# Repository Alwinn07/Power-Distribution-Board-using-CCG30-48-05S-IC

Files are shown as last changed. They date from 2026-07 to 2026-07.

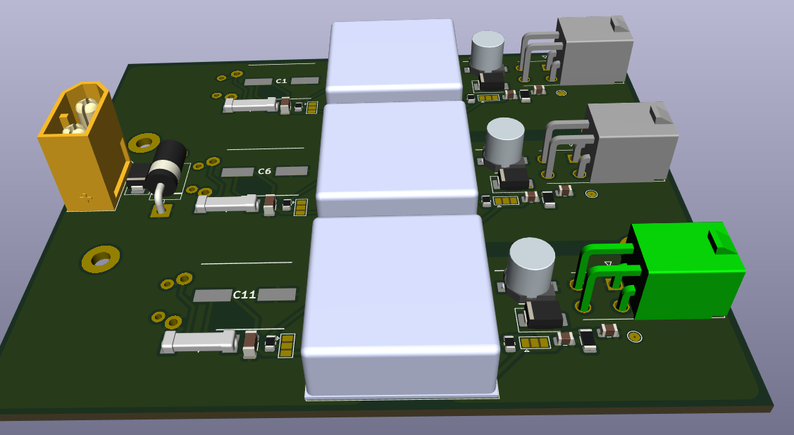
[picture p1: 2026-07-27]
Images/PCB_3D VIEW.png

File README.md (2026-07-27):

# Power-Distribution-Board-using-CCG30-48-05S-IC
An isolated 30 W DC-DC power converter PCB based on the CCG30 module, featuring surge protection, EMI filtering, current limiting, reverse polarity protection, and robust power input circuitry. Designed in KiCad with optimized PCB layout, thermal management, and manufacturability for reliable industrial applications.

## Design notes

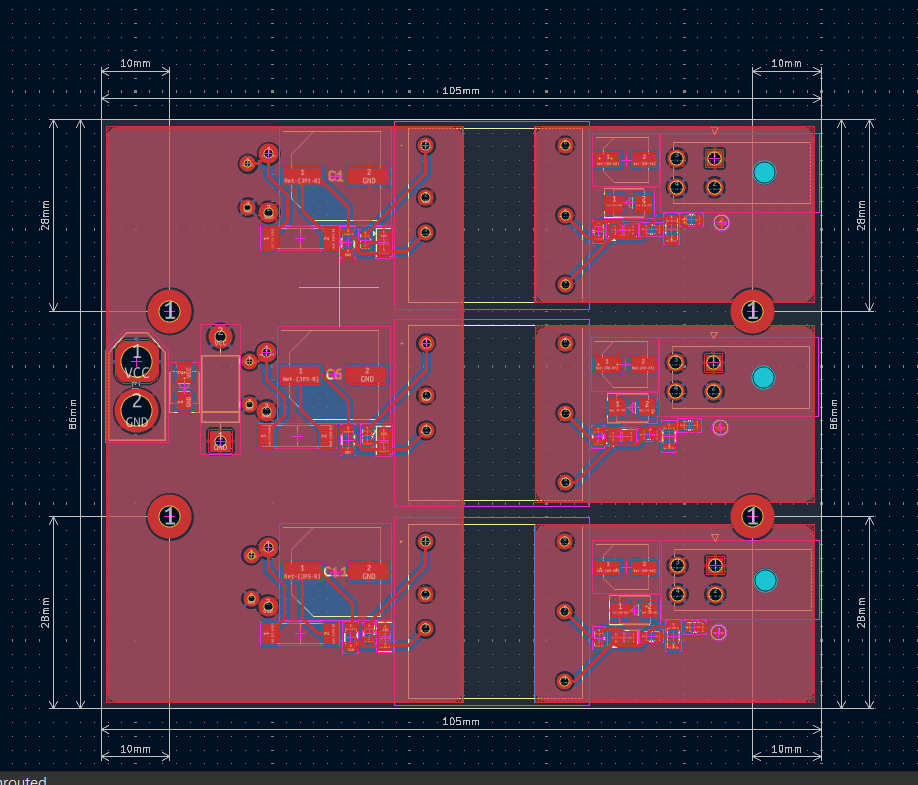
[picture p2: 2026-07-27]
Images/PCB_DESIGN.png

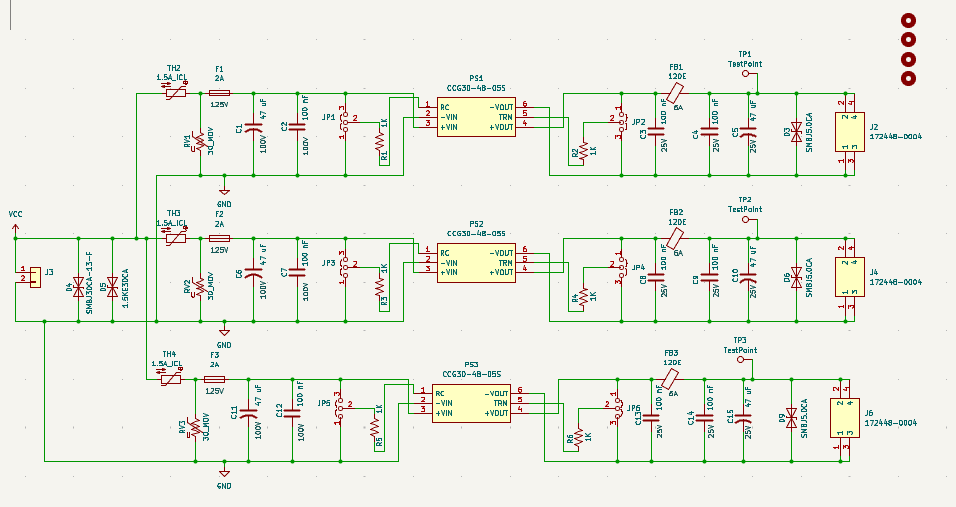
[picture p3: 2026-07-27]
Images/Schematics.png

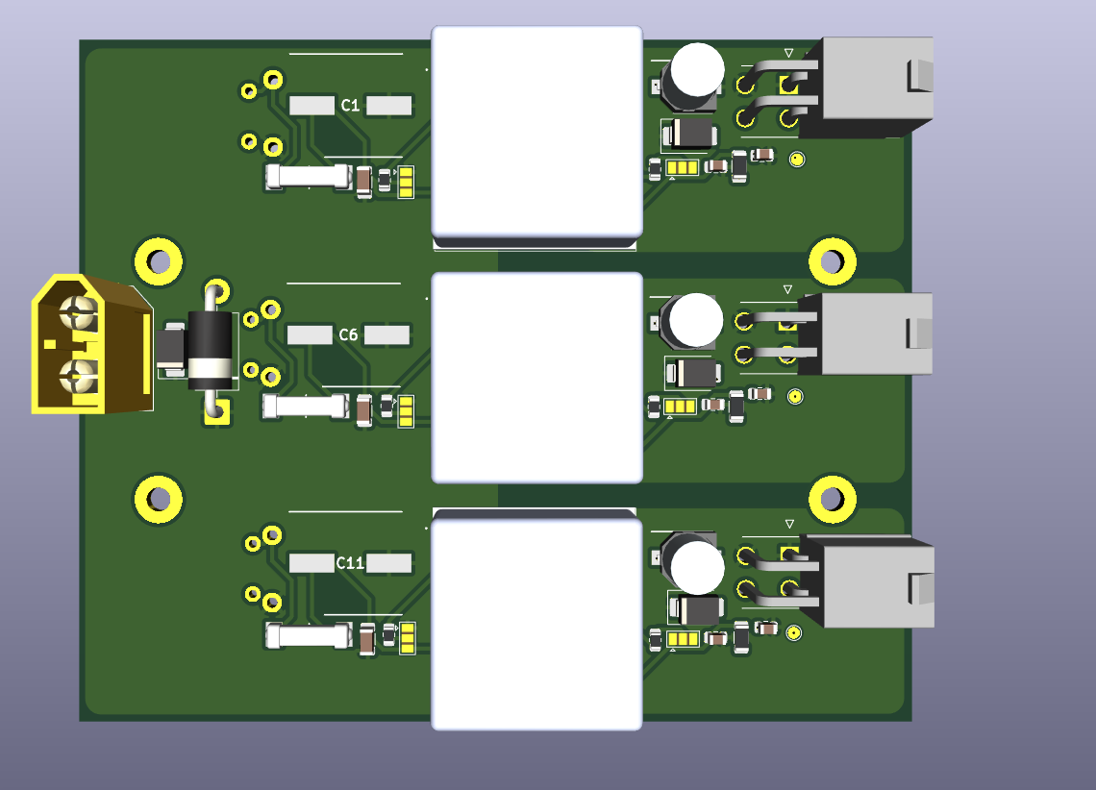
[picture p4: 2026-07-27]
Images/PCB_TOP.png

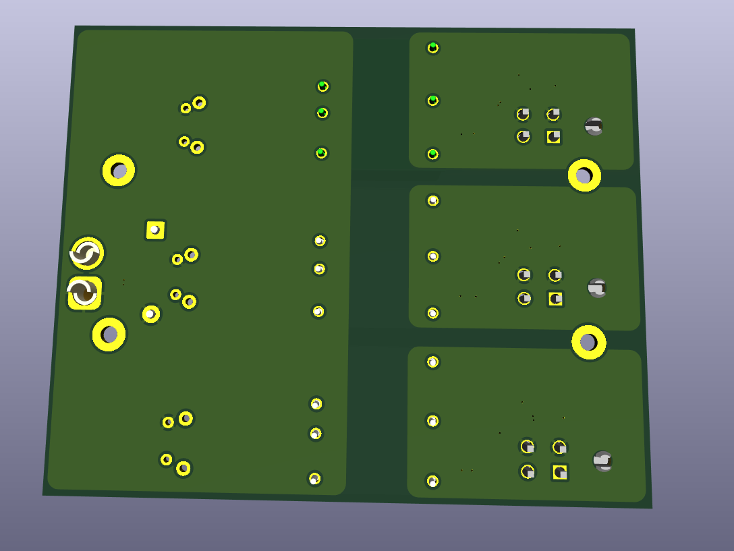
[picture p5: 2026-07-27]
Images/PCB_BACK.png

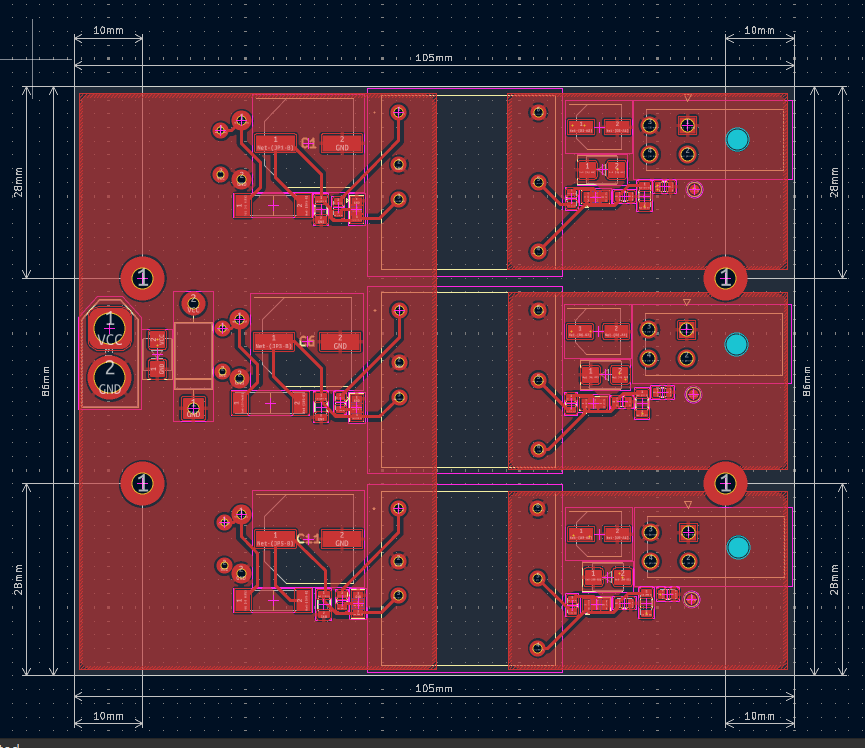
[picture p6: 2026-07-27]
Images/Front Copper.png

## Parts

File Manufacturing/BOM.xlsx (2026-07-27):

S.NO | Reference | Qty | Value | Footprint | Description | Ref Part No: | Alt Ref Part No: | Datasheet
1 | C1,C6,C11 | 3 | 47 uF | inputc:CAPAE1300X1400N | Aluminium Electrolytic Capacitors - SMD 100volts 47uF 12.5X13.5 | EMVE101ARA470MKE0S | EEV-FK2A47DQ | https://www.chemi-con.co.jp/products/relatedfiles/capacitor/catalog/MVERA-e.PDF
2 | C2,C7,C12 | 3 | 100 nF | Capacitor_SMD:C_1206_3216Metric | Multilayer Ceramic Capacitors MLCC - SMD/SMT 0.1 uF 100 VDC 5% 1206 C0G (NP0) | GRM3195C2A104JA01D | CGA5L1C0G2A104J160AE | https://www.mouser.in/datasheet/3/76/2/GRM3195C2A104JA01_01A.pdf
3 | C3,C4,C8,C9,C13,C14 | 6 | 100 nF | Capacitor_SMD:C_0805_2012Metric | Multilayer Ceramic Capacitors MLCC - SMD/SMT 25V .1uF X7R 0805 10 % | KGM21NR71E104KT | C0805C104K3RAC7210 | https://ele.kyocera.com/assets/products/capacitor/KGM_Series_e.pdf
4 | C5,C10,C15 | 3 | 47 uF | OUT_47UF:CAPAE660X730N | Aluminium Electrolytic Capacitors - SMD 25volts 47uF AEC-Q200 | UCW1E470MCL1GS | EXV476M025A9GAA | https://www.mouser.in/datasheet/3/497/1/e_ucw.pdf
5 | D3,D6,D9 | 3 | SMBJ5.0CA | Diode_SMD:D_SMB | ESD Protection Diodes / TVS Diodes 600W 5.0V | SMBJ5.0CA-13-F | SMBJ5.0CA-QH | https://4donline.ihs.com/images/VipMasterIC/IC/DIOD/DIOD-S-A0003133144/DIOD-S-A0003133144-1.pdf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
6 | D4 | 1 | SMBJ30CA-13-F | Diode_SMD:D_SMB | TVS DIODE 30VWM 48.4VC SMB | SMBJ30CA-13-F | SMBJ30CA-E3/52 | https://www.diodes.com/assets/Datasheets/ds19002.pdf
7 | D5 | 1 | 1.5KE30CA | Diode_THT:D_DO-201AD_P15.24mm_Horizontal | TVS DIODE 25.6VWM 41.4VC DO201 | 1.5KE30CA | 1.5KE30CA-E3/51 | https://www.littelfuse.com/assetdocs/littelfuse_tvs_diode_1_5ke_datasheet.pdf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
8 | F1,F2,F3 | 3 | 2A | fuseeee:FUSC10130X300N | FUSE BRD MT 2A 250VAC 125VDC SMD | 3405.0169.24 | TR-1245UMFF2-R | https://www.schurter.com/en/datasheet/typ_UMF_250.pdf
9 | FB1,FB2,FB3 | 3 | 120E | Resistor_SMD:R_1206_3216Metric | FERRITE BEAD 120 OHM 1206 1LN | BBUP00321611121Y00 | BCMS321611A121 RDC01 | https://productfinder.pulseelectronics.com/api/open/part-attachments/datasheet/BBUP00321611121Y00
10 | J2,J4,J6 | 3 | 172448-0004 | connector_out:172448-YY04 | CONN HEADER R/A 4POS 4.2MM | 172448-0004 | G874D041202CEU | https://www.molex.com/pdm_docs/sd/1724480002_sd.pdf
11 | J3 | 1 | Conn_01x02 | Connector_AMASS:AMASS_XT60-M_1x02_P7.20mm_Vertical | XT60 Male DC Power Plug, 2-Pin, 35A/500V, Solder Terminals | SKU: R150150 | XT60U-M.G.Y. | https://www.tme.eu/Document/2d152ced3b7a446066e6c419d84bb460/XT60%20SPEC.pdf
12 | PS1,PS2,PS3 | 3 | CCG30-48-05S | cccggg:CCG304815S | DC DC CONVERTER 5V 30W | CCG30-48-05S |  | https://product.tdk.com/system/files/dam/doc/product/power/switching-power/dc-dc-converter/catalog/ccg_e.pdf
13 | R1,R2,R3,R4,R5,R6 | 6 | 1K | Resistor_SMD:R_0805_2012Metric | RES 1 KOHM 1% 1/4W 0805 | AC0805FR-7W1KL | RK73H2ATTD1001F | https://yageogroup.com/content/datasheet/asset/file/PYU-AC_51_ROHS_L
14 | RV1,RV2,RV3 | 3 | 30_MOV | 47uf:varistor.pretty | VARISTOR 39V 5KA DISC 20MM | V20P25AUTO | V20E25AUTO | https://www.littelfuse.com/assetdocs/littelfuse-varistor-aumov-datasheet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
15 | TH2,TH3,TH4 | 3 | 1.5A_ICL | 47uf:icl.pretty | ICL 30 OHM 25% 1.5A 10.16MM | CL-210 | ICL 16 OHM 25% 2.7A 13.97MM | https://www.amphenol-sensors.com/hubfs/Documents/AAS-920-325D-Thermometrics-NTC-Inrush-031814-web.pdf?id=90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
16 | TP1,TP2,TP3 | 3 | TestPoint | TestPoint:TestPoint_Pad_D1.5mm | PC TEST POINT LOOP | KEYSTONE 1038 | KEYSTONE 1038 | https://www.keyelco.com/userAssets/file/K75p63.pdf

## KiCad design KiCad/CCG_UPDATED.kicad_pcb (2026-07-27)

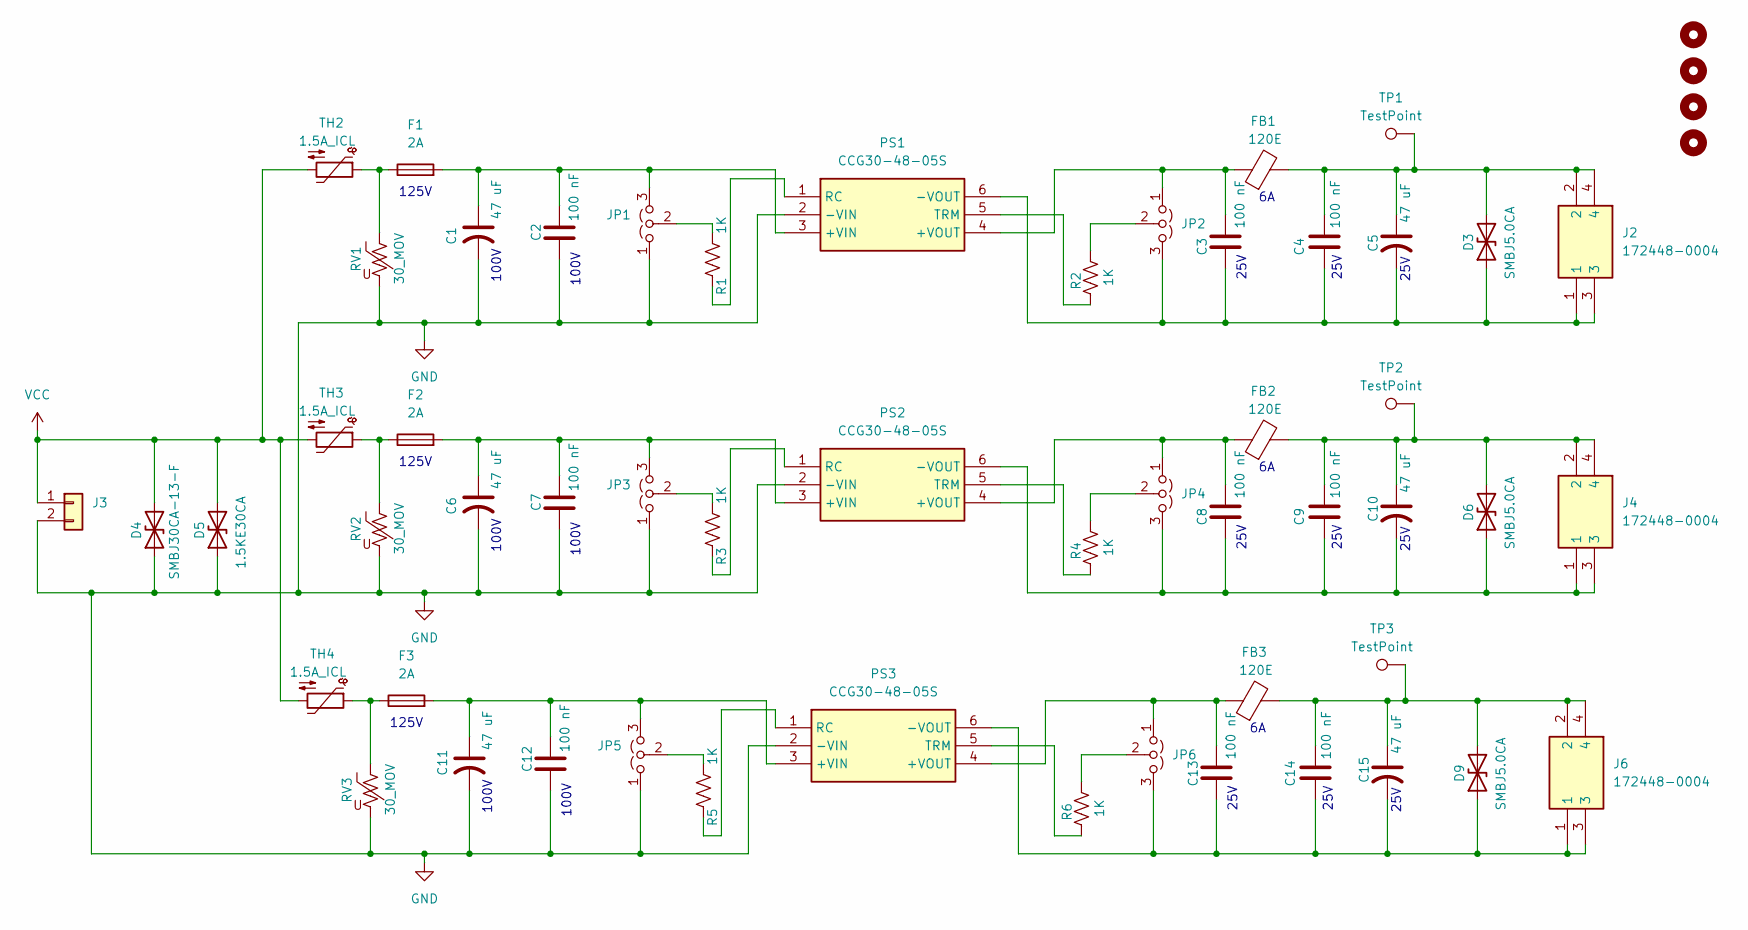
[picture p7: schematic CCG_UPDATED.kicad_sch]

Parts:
C1, C6, C11: 47 uF; CAPAE1300X1400N
C2, C7, C12: 100 nF; C_1206_3216Metric
C3, C4, C8, C9, C13, C14: 100 nF; C_0805_2012Metric
C5, C10, C15: 47 uF; CAPAE660X730N
D3, D6, D9: SMBJ5.0CA; D_SMB
D4: SMBJ30CA-13-F; D_SMB
D5: 1.5KE30CA; D_DO-201AD_P15.24mm_Horizontal
F1, F2, F3: 2A; FUSC10130X300N
FB1, FB2, FB3: 120E; R_1206_3216Metric
H1, H2, H3, H4: MountingHole; MountingHole_3mm_Pad
J2, J4, J6: 172448-0004; 172448-YY04; Mouser Part Number 538-172448-0004
J3: Conn_01x02; AMASS_XT60-M_1x02_P7.20mm_Vertical
JP1, JP2, JP3, JP4, JP5, JP6: Jumper_3_Open; SolderJumper-3_P1.3mm_Open_Pad1.0x1.5mm
PS1, PS2, PS3: CCG30-48-05S; CCG304815S; Mouser Part Number 967-CCG304805S
R1, R2, R3, R4, R5, R6: 1K; R_0805_2012Metric
RV1, RV2, RV3: 30_MOV; varistor.pretty
TH2, TH3, TH4: 1.5A_ICL; icl.pretty
TP1, TP2, TP3: TestPoint; TestPoint_Pad_D1.5mm

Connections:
GND: C1.2, C2.2, C6.2, C7.2, C11.2, C12.2, D4.1 (A1), D5.1 (A1), J3.2, JP1.1 (A), JP3.1 (A), JP5.1 (A), PS1.2 (-VIN), PS2.2 (-VIN), PS3.2 (-VIN), RV1.2, RV2.2, RV3.2
unnamed: C3.2, C4.2, C5.2, D3.1 (A1), J2.1, J2.3, JP2.3 (B), PS1.6 (-VOUT)
unnamed: C4.1, C5.1, D3.2 (A2), FB1.2, J2.2, J2.4, TP1.1 (1_1)
unnamed: C8.2, C9.2, C10.2, D6.1 (A1), J4.1, J4.3, JP4.3 (B), PS2.6 (-VOUT)
unnamed: C9.1, C10.1, D6.2 (A2), FB2.2, J4.2, J4.4, TP2.1 (1_1)
unnamed: C13.2, C14.2, C15.2, D9.1 (A1), J6.1, J6.3, JP6.3 (B), PS3.6 (-VOUT)
unnamed: C14.1, C15.1, D9.2 (A2), FB3.2, J6.2, J6.4, TP3.1 (1_1)
unnamed: F1.1, RV1.1, TH2.1
unnamed: F2.1, RV2.1, TH3.1
unnamed: F3.1, RV3.1, TH4.1
unnamed: C1.1, C2.1, F1.2, JP1.3 (B), PS1.3 (+VIN)
unnamed: JP1.2 (C), R1.1
unnamed: C3.1, FB1.1, JP2.1 (A), PS1.4 (+VOUT)
unnamed: JP2.2 (C), R2.1
unnamed: C6.1, C7.1, F2.2, JP3.3 (B), PS2.3 (+VIN)
unnamed: JP3.2 (C), R3.1
unnamed: C8.1, FB2.1, JP4.1 (A), PS2.4 (+VOUT)
unnamed: JP4.2 (C), R4.1
unnamed: C11.1, C12.1, F3.2, JP5.3 (B), PS3.3 (+VIN)
unnamed: JP5.2 (C), R5.1
unnamed: C13.1, FB3.1, JP6.1 (A), PS3.4 (+VOUT)
unnamed: JP6.2 (C), R6.1
unnamed: PS1.1 (RC), R1.2
unnamed: PS1.5 (TRM), R2.2
unnamed: PS2.1 (RC), R3.2
unnamed: PS2.5 (TRM), R4.2
unnamed: PS3.1 (RC), R5.2
unnamed: PS3.5 (TRM), R6.2
VCC: D4.2 (A2), D5.2 (A2), J3.1, TH2.2, TH3.2, TH4.2

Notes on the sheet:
125V
25V
100V

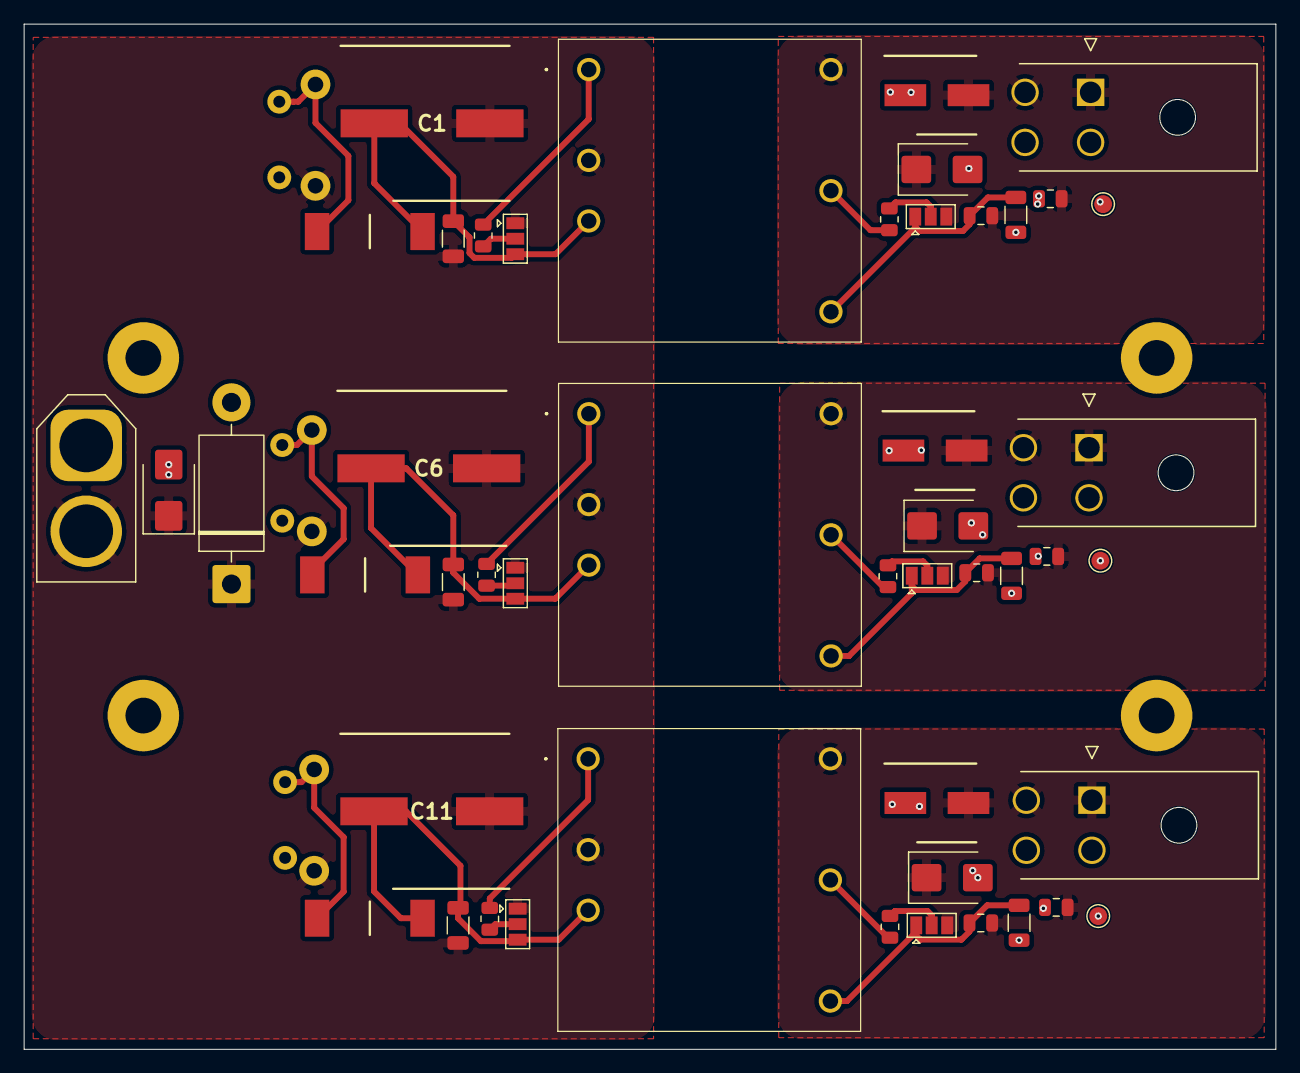
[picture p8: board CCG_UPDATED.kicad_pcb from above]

Board: 2 copper layers, 105.0 x 86.0 mm, 58 parts (0 on the bottom side), 29 nets.
